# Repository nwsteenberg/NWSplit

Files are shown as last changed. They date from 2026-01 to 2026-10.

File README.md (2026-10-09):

# NWSplit

> A 52-key, column-staggered split ergonomic keyboard developed almost entirely through **Ergogen**.

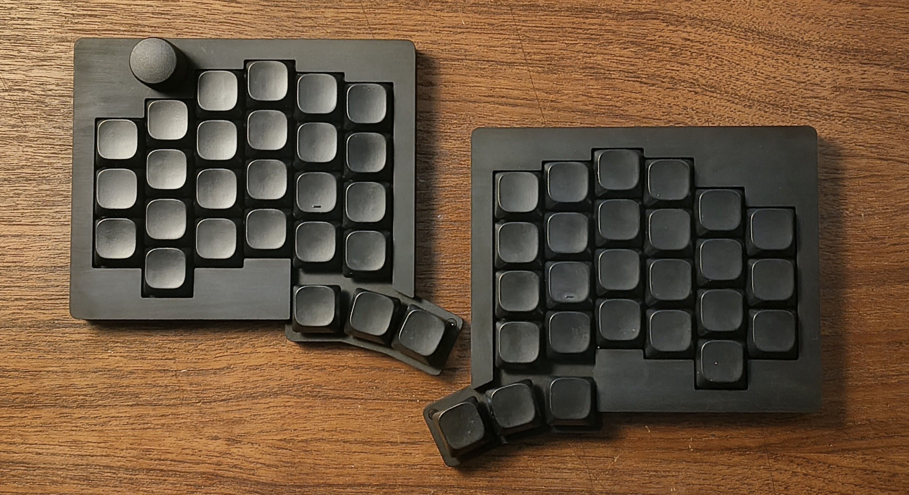
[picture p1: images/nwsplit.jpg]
NWSplit Keyboard


The goal: build the *perfect* keyboard for me. Of course, getting there meant going through a handful of prototypes that didn't quite make the cut. Take a look at the [Graveyard](images/graveyard) to see the keyboards that didn't make the cut.

---

## ✨ Features
* **Declarative:** Designed in [Ergogen](https://ergogen.xyz/) (both case and PCB).
* **Firmware:** Powered by **QMK & VIAL** for real-time keymap customization without flashing.
* **Choc Switches:** Hot-swap support for Kailh Choc v1 and v2 switches.
* **Per-Key RGB:** SK6812 MINI-E lighting support.
* **Extra Inputs:** Optional rotary encoder support (up to 2).

---

## 📂 Repository Structure

* `3d/` — 3D printable models (`.stl`) for the keyboard and expansion modules.
* `firmware/` — Vial/QMK firmware source files and layouts.
* `footprints/` — Custom Ergogen and KiCad footprints.
* `images/` — Renders, wiring diagrams, and build photos.
* `production/` — Ready-to-use PCB production files (Gerbers).
* `traced-pcbs/` — Autogenerated and manually traced KiCad PCB projects.
* `keyboard.yaml` — Ergogen configuration file for the main keyboard.
* `expansion.yaml` — Ergogen configuration file for the expansion modules.

---

## 🛒 Bill of Materials (BOM)

| Component | Description | Quantity | Notes |
| :--- | :--- | :---: | :--- |
| **PCB** | Gerber available in `production/` | 2 | Reversible (left and right use the exact same PCB) |
| **Diodes** | 1N4148, SOD123 | 52 | |
| **MCU** | Waveshare RP2040-Zero | 2 | Clones work too just verify pinout compatibility |
| **TRRS Connector** | PJ320A Jack | 2 | |
| **Switches** | Kailh Choc V1/V2 | 52 | Dont use V2 with guide pin (stock red/blue/brown) |
| **Keycaps** | Low-profile keycaps of choice | 52 | THT or LPF profiles recommended |
| **Heat Inserts** | M2 L3 OD3.5 (or OD3 for resin prints) | 12 | |
| **Per-Key LEDs** | SK6812 MINI-E | 52 | *Optional* |
| **Rotary Encoder** | EC11 / EC12 | 0–2 | *Optional* (supports button click) |
| **Pogo Connectors** | Angled 6-pin Magnetic Pogo Pins | 0–2 | *Optional* (used for experimental modular connections) |

---

## 🚀 Roadmap & TODO

- [ ] **Build Instructions:** Step-by-step assembly guide.
- [ ] **Sandwitch case:** Cheap case option without 3d printing.
- [ ] **Expansion Boards:** 
  - [ ] Trackball module
  - [ ] Trackpad module
- [ ] **Images:** Add build process and final images of the keyboard and expansions.
- [ ] **Graveyard:** Show what keyboards didn't make the cut.

---

## 💡 Inspiration

Throughout the journey the following projects provided a ton of inspiration to create the version of the keyboard as it is today:
* [christianselig/caldera](https://christianselig.com/2024/07/caldera-keyboard/)
* [achyudh/karma](https://github.com/achyudh/karma)
* [carrefinho/forager](https://github.com/carrefinho/forager)

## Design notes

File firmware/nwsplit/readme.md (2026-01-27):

# nwsplit60

NWSplit

*A short description of the keyboard/project*

* Keyboard Maintainer: [Nikolaj W. Steenberg](https://github.com/nwsteenberg)
* Hardware Supported: RP2040 @TODO

Make example for this keyboard (after setting up your build environment):

    make nwsplit:default

Flashing example for this keyboard:

    make nwsplit:default:flash

See the [build environment setup](https://docs.qmk.fm/#/getting_started_build_tools) and the [make instructions](https://docs.qmk.fm/#/getting_started_make_guide) for more information. Brand new to QMK? Start with our [Complete Newbs Guide](https://docs.qmk.fm/#/newbs).

## Bootloader

Enter the bootloader in 3 ways:

* **Bootmagic reset**: Hold down the key at (0,0) in the matrix (usually the top left key or Escape) and plug in the keyboard
* **Physical reset button**: Briefly press the button on the back of the PCB - some may have pads you must short instead
* **Keycode in layout**: Press the key mapped to `QK_BOOT` if it is available

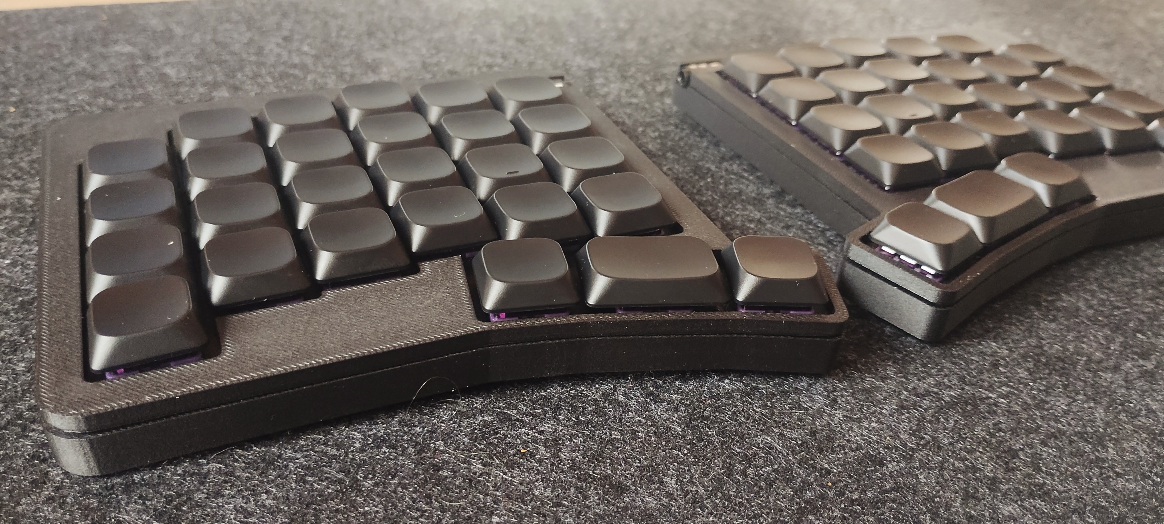
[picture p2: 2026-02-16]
images/graveyard/nwsplit_rev4_2.jpg

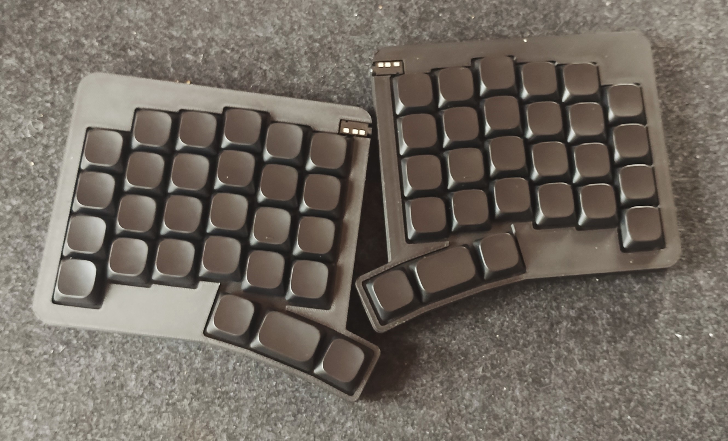
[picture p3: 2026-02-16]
images/graveyard/nwsplit_rev4.jpg

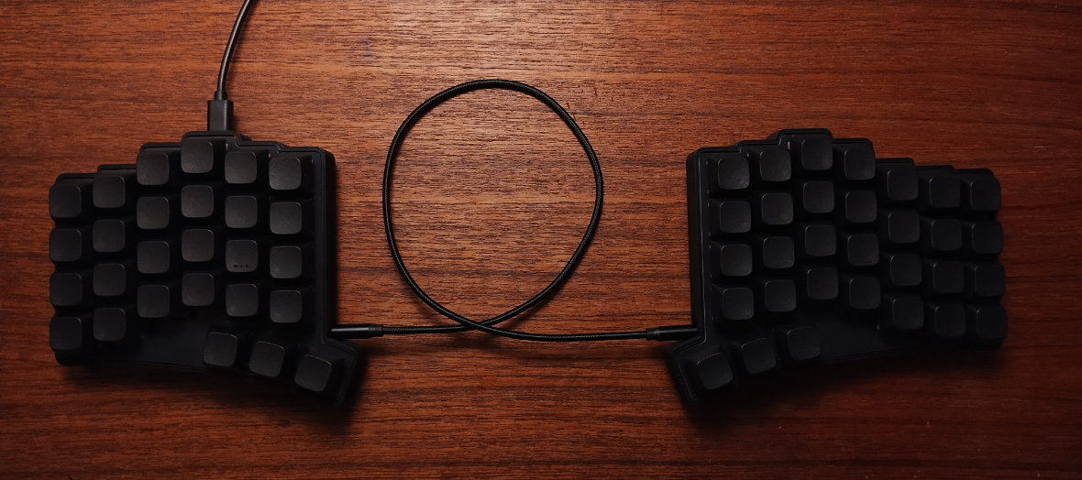
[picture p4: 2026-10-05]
images/graveyard/nwsplit_rev2.png

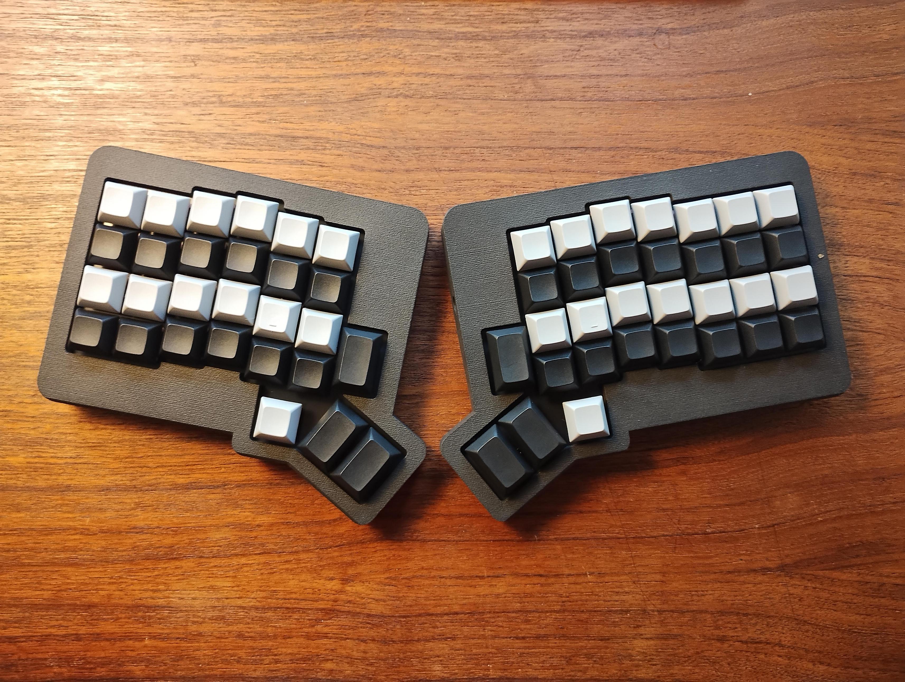
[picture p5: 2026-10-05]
images/graveyard/nwsplit_rev3.jpeg

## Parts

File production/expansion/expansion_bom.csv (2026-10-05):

Designator | Footprint | Quantity | Value | LCSC Part #
C1 | FPC-SMD_FPC05006-09200 | 1 | FPC-SMD_FPC05006-09200 | C479749

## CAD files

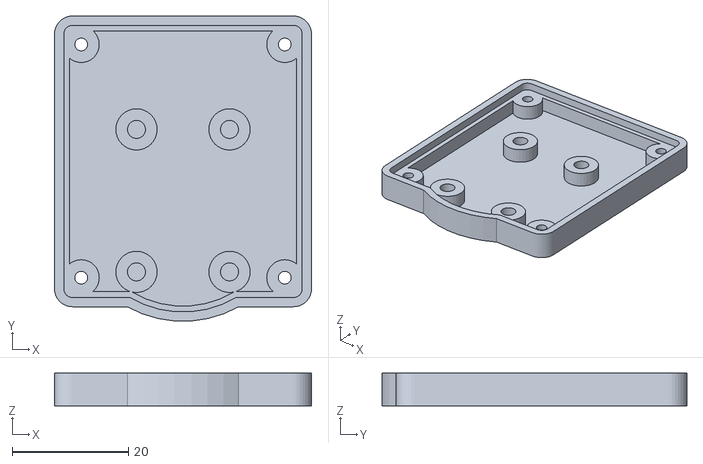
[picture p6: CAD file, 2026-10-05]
3d/expansion/trackball/trackballBase.stl
44.2 x 52.4 x 5.60

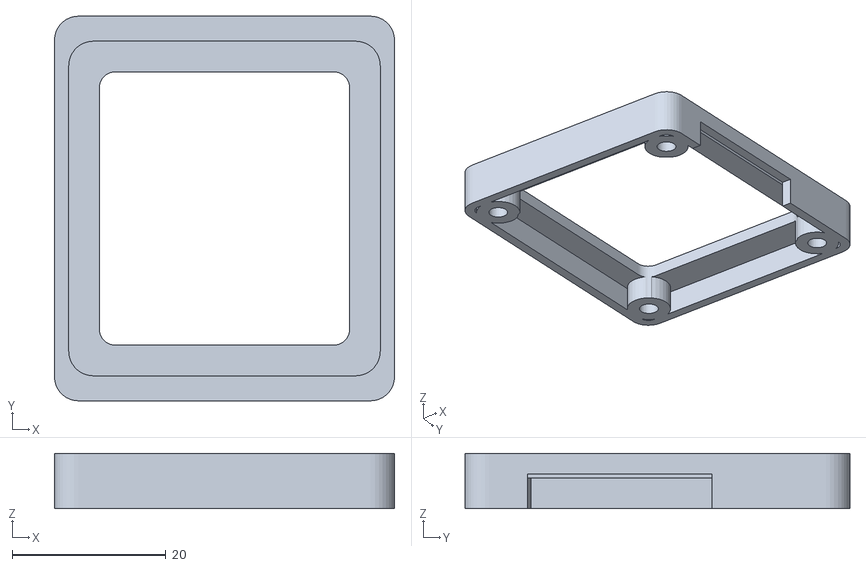
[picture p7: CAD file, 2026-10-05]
3d/expansion/trackpad/trackpadTop.stl
44.2 x 50.0 x 7.20

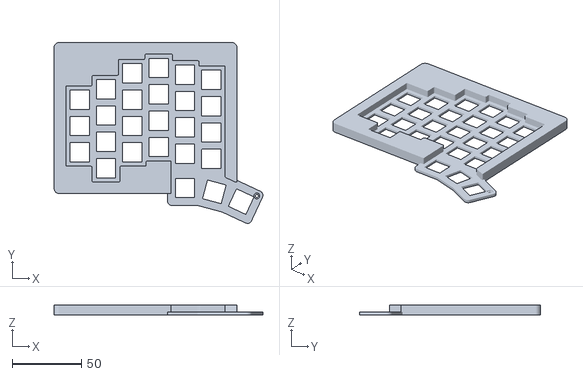
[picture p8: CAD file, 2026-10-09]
3d/keyboard/topLeft.stl
150.7 x 130.4 x 7.20

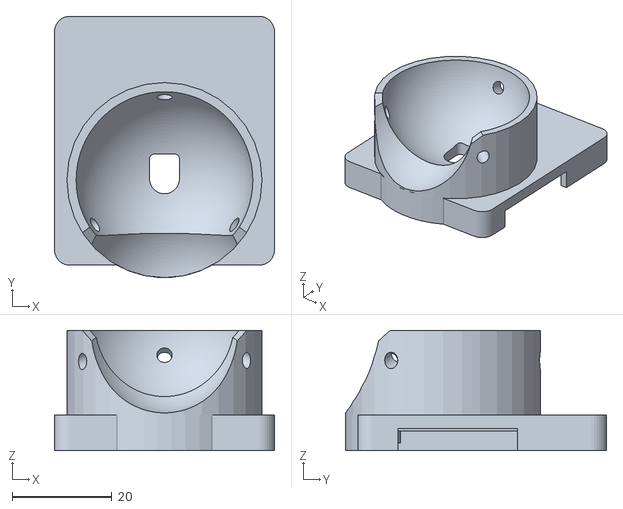
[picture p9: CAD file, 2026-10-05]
3d/expansion/trackball/trackballTop2.stl
44.2 x 52.5 x 24.2

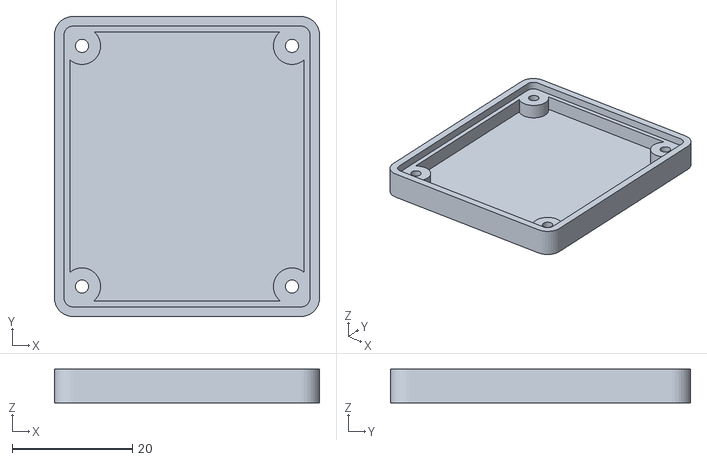
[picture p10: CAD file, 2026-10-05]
3d/expansion/trackpad/trackpadBase.stl
44.2 x 50.0 x 5.60

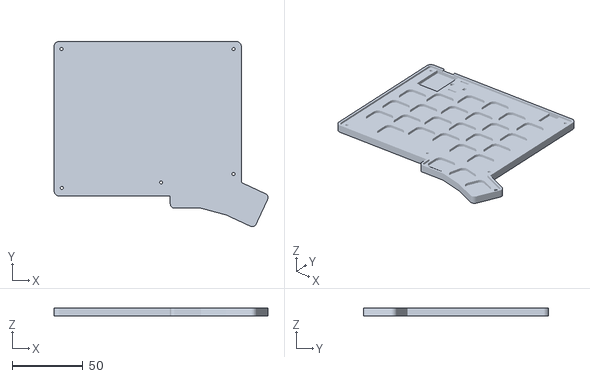
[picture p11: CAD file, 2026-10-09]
3d/keyboard/bottomLeft.stl
150.7 x 130.4 x 5.60

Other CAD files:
3d/keyboard/topRightEncoder.stl
3d/expansion/trackball/trackballTop.stl
3d/keyboard/topLeftEncoder.stl
3d/keyboard/bottomRight.stl
3d/keyboard/topRight.stl
3d/expansion/trackball/trackballTop.blend

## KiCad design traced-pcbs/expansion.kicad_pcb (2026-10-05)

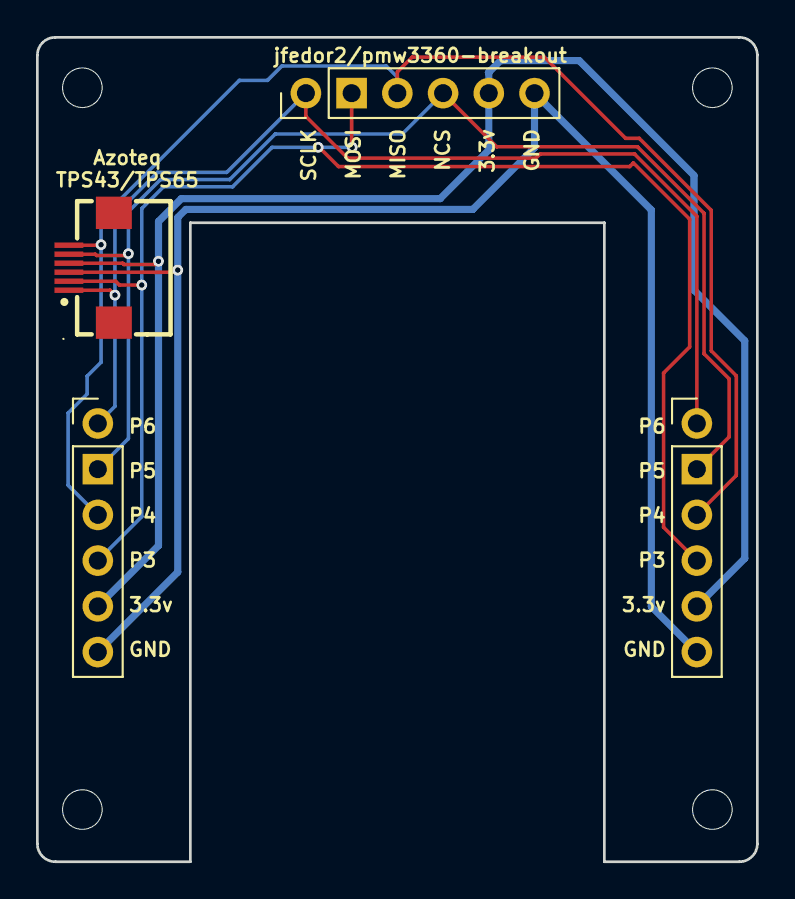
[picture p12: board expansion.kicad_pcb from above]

Board: 2 copper layers, 40.0 x 45.8 mm, 8 parts (0 on the bottom side), 6 nets.

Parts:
C1: FPC-SMD_FPC05006-09200
MH1, MH2, MH3, MH4: mounting_hole_npth
Pin Header 2.54 1x61, Pin Header 2.54 1x62, Pin Header 2.54 1x63: PinHeader_1x06_P2.54mm_Vertical

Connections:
GND: C1.3, Pin Header 2.54 1x61.6, Pin Header 2.54 1x62.6, Pin Header 2.54 1x63.6
P1: C1.1, Pin Header 2.54 1x61.1, Pin Header 2.54 1x62.1, Pin Header 2.54 1x63.1
P2: C1.5, Pin Header 2.54 1x61.2, Pin Header 2.54 1x62.2, Pin Header 2.54 1x63.4
P3: C1.6, Pin Header 2.54 1x61.3, Pin Header 2.54 1x62.3, Pin Header 2.54 1x63.3
P3V3: C1.4, Pin Header 2.54 1x61.5, Pin Header 2.54 1x62.5, Pin Header 2.54 1x63.5
P4: C1.2, Pin Header 2.54 1x61.4, Pin Header 2.54 1x62.4, Pin Header 2.54 1x63.2

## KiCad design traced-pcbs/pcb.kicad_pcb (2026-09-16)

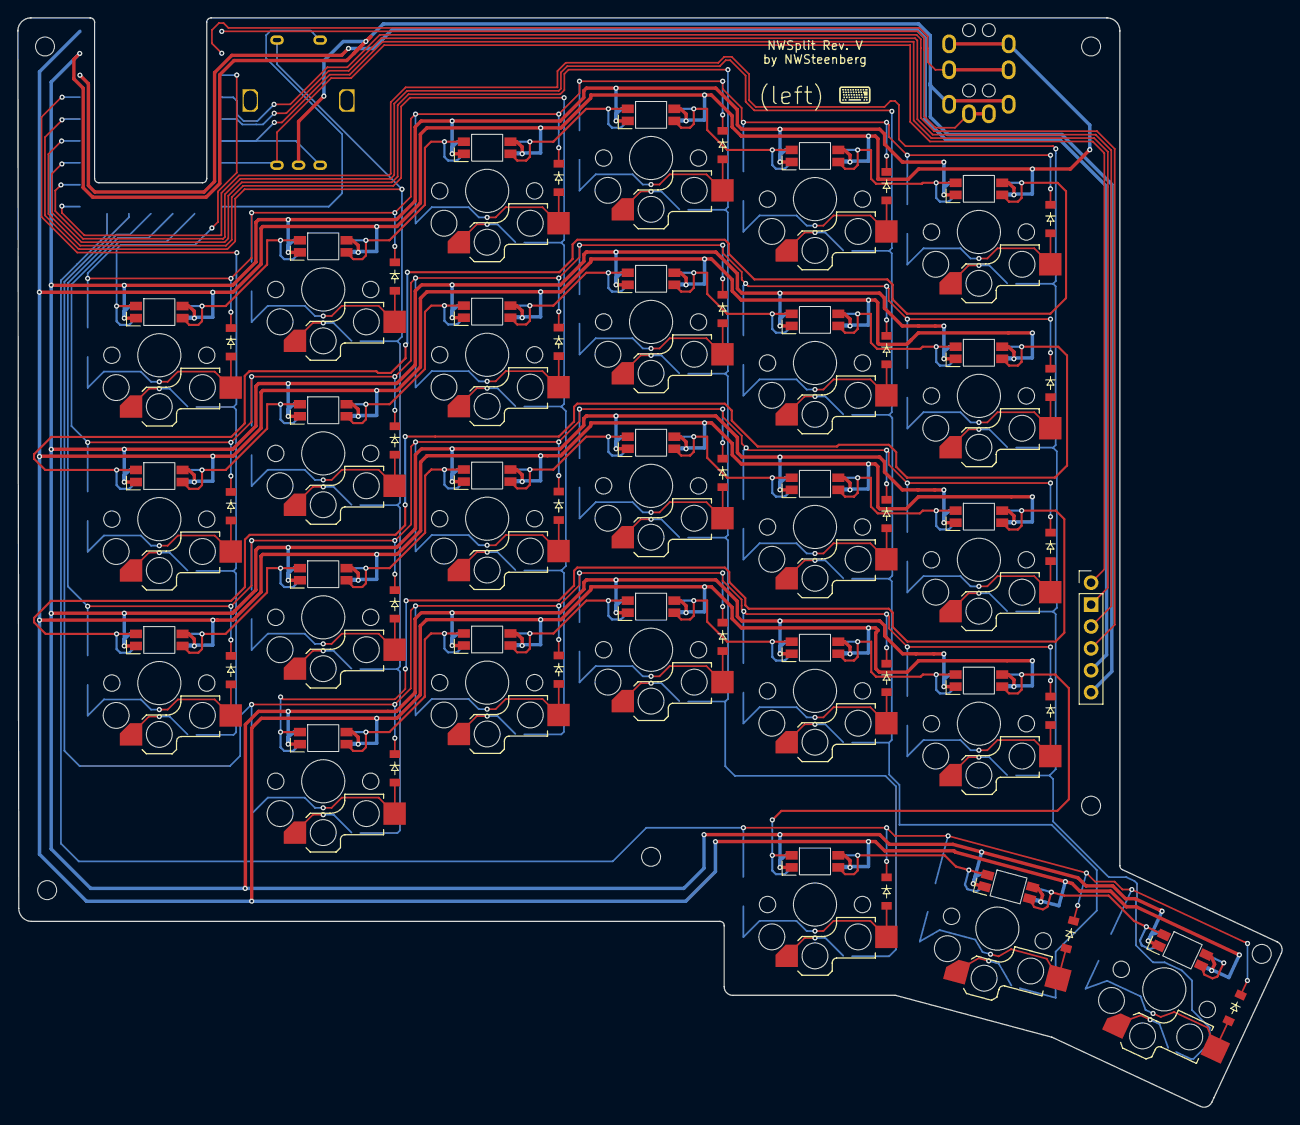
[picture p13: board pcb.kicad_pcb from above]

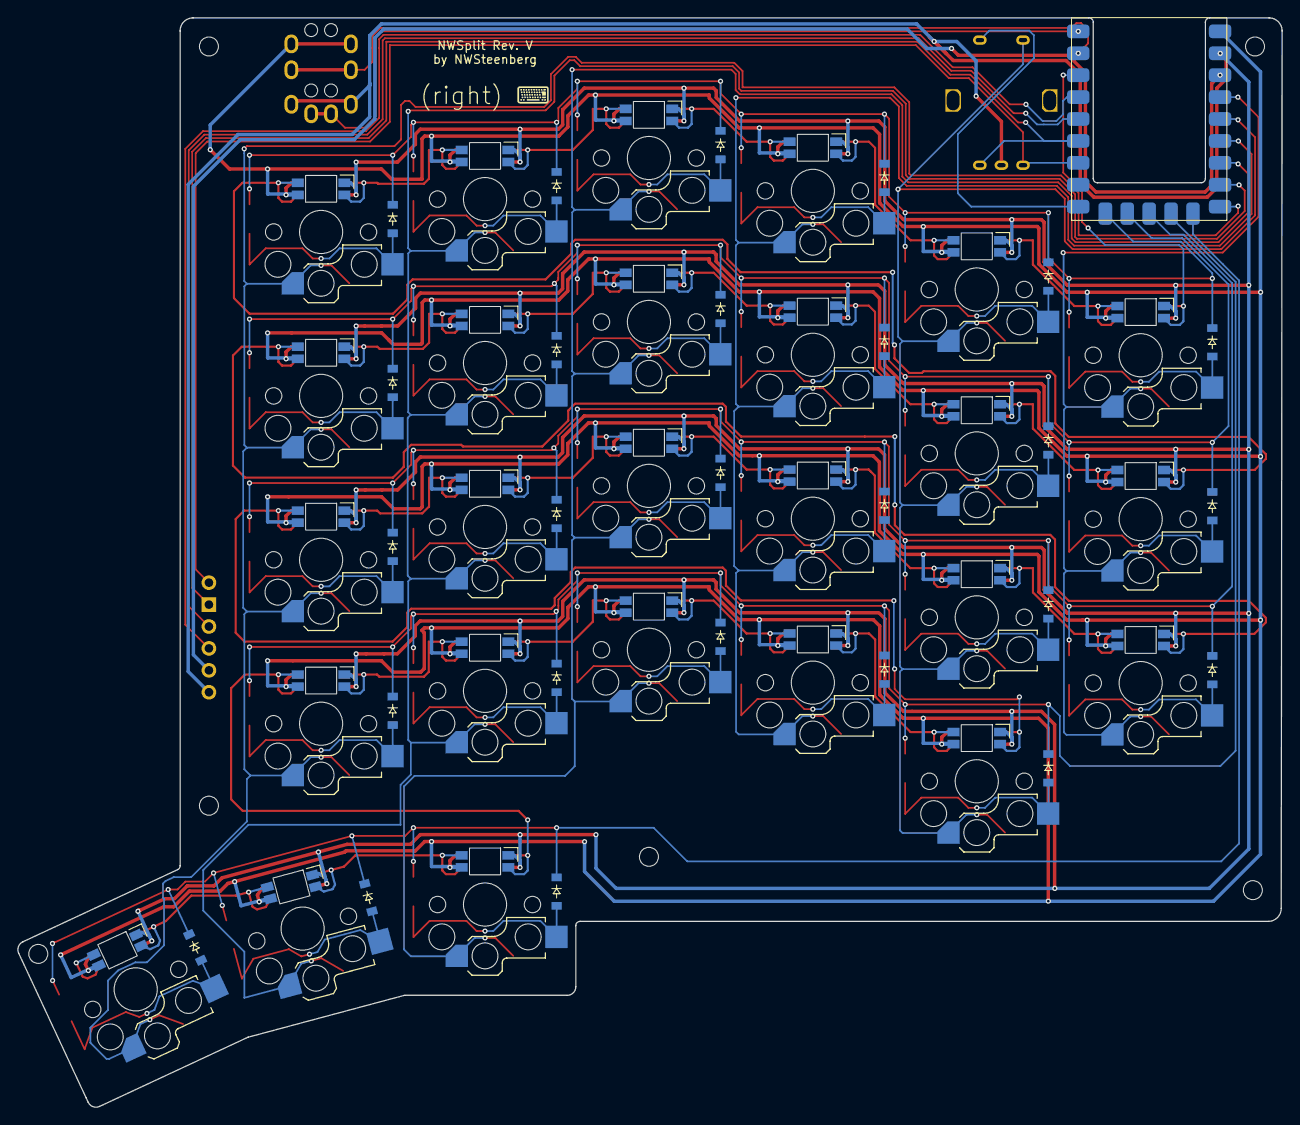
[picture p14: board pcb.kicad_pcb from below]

Board: 2 copper layers, 146.5 x 126.3 mm, 113 parts (78 on the bottom side), 42 nets.

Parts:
D1, D2, D3, D4, D5, D6, D7, D8, D9, D10, D11, D12, D13, D14, D15, D16, D17, D18, D19, D20, D21, D22, D23, D24, D25, D26, D27, D28, D29, D30, D31, D32, D33, D34, D35, D36, D37, D38, D39, D40, D41, D42, D43, D44, D45, D46, D47, D48, D49, D50, D51, D52: diode_tht_sod123
LED1, LED2, LED3, LED4, LED5, LED6, LED7, LED8, LED9, LED10, LED11, LED12, LED13, LED14, LED15, LED16, LED17, LED18, LED19, LED20, LED21, LED22, LED23, LED24, LED25, LED26: led_SK6812mini-e (per-key, reversible)
MH1, MH2, MH3, MH4, MH5, MH6: mounting_hole_npth
Pin Header 2.54 1x61: PinHeader_1x06_P2.54mm_Vertical
RE1: rotary_encoder_ec11_ec12
S1, S2, S3, S4, S5, S6, S7, S8, S9, S10, S11, S12, S13, S14, S15, S16, S17, S18, S19, S20, S21, S22, S23, S24, S25, S26: switch_choc_v1_v2
TRRS1: trrs_pj320a (reversible)

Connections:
GND: LED1.3, LED2.3, LED3.3, LED4.3, LED5.3, LED6.3, LED7.3, LED8.3, LED9.3, LED10.3, LED11.3, LED12.3, LED13.3, LED14.3, LED15.3, LED16.3, LED17.3, LED18.3, LED19.3, LED20.3, LED21.3, LED22.3, LED23.3, LED24.3, LED25.3, LED26.3, Pin Header 2.54 1x61.6, RE1.B, TRRS1.4
GP5: Pin Header 2.54 1x61.2, RE1.A
GP6: Pin Header 2.54 1x61.1, RE1.C
GP9: D3.1, D7.1, D11.1, D15.1, D19.1, D23.1, D29.1, D33.1, D37.1, D41.1, D45.1, D49.1
GP10: D2.1, D6.1, D10.1, D14.1, D18.1, D22.1, D28.1, D32.1, D36.1, D40.1, D44.1, D48.1
GP11: D1.1, D5.1, D9.1, D13.1, D17.1, D21.1, D27.1, D31.1, D35.1, D39.1, D43.1, D47.1
GP12: D4.1, D8.1, D12.1, D16.1, D20.1, D30.1, D34.1, D38.1, D42.1, D46.1
GP13: D24.1, D25.1, D26.1, D50.1, D51.1, D52.1
GP14: S20.1, S21.1, S22.1, S23.1, S26.1
GP15: S16.1, S17.1, S18.1, S19.1, S25.1
GP26: S12.1, S13.1, S14.1, S15.1, S24.1
GP27: S8.1, S9.1, S10.1, S11.1
GP28: RE1.S1, S4.1, S5.1, S6.1, S7.1
GP29: S1.1, S2.1, S3.1
LED_NET: LED1.2, LED2.2, LED2.4, LED3.2, LED3.4, LED4.2, LED4.4, LED5.2, LED5.4, LED6.2, LED6.4, LED7.2, LED7.4, LED8.2, LED8.4, LED9.2, LED9.4, LED10.2, LED10.4, LED11.2, LED11.4, LED12.2, LED12.4, LED13.2, LED13.4, LED14.2, LED14.4, LED15.2, LED15.4, LED16.2, LED16.4, LED17.2, LED17.4, LED18.2, LED18.4, LED19.2, LED19.4, LED20.2, LED20.4, LED21.2, LED21.4, LED22.2, LED22.4, LED23.2, LED23.4, LED24.2, LED24.4, LED25.2, LED25.4, LED26.2, LED26.4
P5V: LED1.1, LED2.1, LED3.1, LED4.1, LED5.1, LED6.1, LED7.1, LED8.1, LED9.1, LED10.1, LED11.1, LED12.1, LED13.1, LED14.1, LED15.1, LED16.1, LED17.1, LED18.1, LED19.1, LED20.1, LED21.1, LED22.1, LED23.1, LED24.1, LED25.1, LED26.1, TRRS1.2
center_only: D25.2, D51.2, S25.2
index_bottom: D16.2, D42.2, S16.2
index_home: D17.2, D43.2, S17.2
index_num: D19.2, D45.2, S19.2
index_top: D18.2, D44.2, S18.2
inner_bottom: D20.2, D46.2, S20.2
inner_home: D21.2, D47.2, S21.2
inner_num: D23.2, D49.2, S23.2
inner_only: D24.2, D50.2, S24.2
inner_top: D22.2, D48.2, S22.2
middle_bottom: D12.2, D38.2, S12.2
middle_home: D13.2, D39.2, S13.2
middle_num: D15.2, D41.2, S15.2
middle_top: D14.2, D40.2, S14.2
outer_home: D1.2, D27.2, S1.2
outer_num: D3.2, D29.2, S3.2
outer_only: D26.2, D52.2, S26.2
outer_top: D2.2, D28.2, S2.2
pinky_bottom: D4.2, D30.2, S4.2
pinky_home: D5.2, D31.2, S5.2
pinky_num: D7.2, D33.2, S7.2
pinky_top: D6.2, D32.2, S6.2
ring_bottom: D8.2, D34.2, S8.2
ring_home: D9.2, D35.2, S9.2
ring_num: D11.2, D37.2, S11.2
ring_top: D10.2, D36.2, S10.2

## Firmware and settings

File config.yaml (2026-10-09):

units:
  outlinePadding: 1

  plateThickness: 1.6
  pcbThickness: 1.6

  keyCutoutDimentions: 13.95

  # Case
  baseHeight: 3
  screwRadius: 1.1 # M2 + 0.2mm buffer
  screwHoleRadius: 1.55
  screwHoleWallThickness: 2
  screwHeadRadius: 2.1 # 4mm + 0.2mm buffer
  fromPlateToTop: 5

  baseWallHeight: baseHeight + pcbThickness
  topWallHeight: 2.2
  wallThickness: 1.6

points:
  zones:
    matrix:
      anchor:
        shift: [40, -180] # Move into KiCAD position
      columns:
        outer.key.column_net: "GP29"
        outer.rows.bottom.skip: true

        pinky.key.column_net: "GP28"
        pinky.key.stagger: 0.4U

        ring.key.column_net: "GP27"
        ring.key.stagger: 0.6U

        middle.key.column_net: "GP26"
        middle.key.stagger: 0.2U

        index.key.column_net: "GP15"
        index.key.stagger: -0.25U

        inner.key.column_net: "GP14"
        inner.key.stagger: -0.2U
      rows:
        bottom.row_net: "GP12"
        home.row_net: "GP11"
        top.row_net: "GP10"
        num.row_net: "GP9"
    thumb:
      anchor:
        ref: matrix_index_bottom
        shift: [0U, -1.3U]
      columns:
        inner:
          key.name: matrix_thumb_inner
          key.column_net: "GP26"
          key.origin: [-0.5U, -0.5U]
        center:
          key.name: matrix_thumb_center
          key.column_net: "GP15"
          key.splay: -15
          key.origin: [-0.5U, -0.5U]
        outer:
          key.name: matrix_thumb_outer
          key.column_net: "GP14"
          key.splay: -10
          key.origin: [-0.5U, -0.5U]
      rows:
        only:
          row_net: "GP13"
    screw_1:
      anchor:
        - ref: matrix_inner_bottom
          shift: [13, -9.5]
    screw_2:
      anchor:
        - ref: matrix_inner_num
          shift: [13, 21.5]
    screw_3:
      anchor:
        - ref: matrix_inner_num
          shift: [-5U-13, 21.5]
    screw_4:
      anchor:
        - ref: matrix_outer_home
          shift: [-13, -24]
    screw_5:
      anchor:
        - ref: matrix_middle_bottom
          shift: [0, -24]
    screw_thumb:
      anchor:
        - ref: matrix_thumb_outer
          shift: [8.5, 8.5]
    knob:
      anchor:
        - ref: matrix_pinky_num
          shift: [-0.15U, 1.15U]
      columns.only.key.column_net: "GP28"
      rows.only.row_net: "GP8"
  mirror:
    ref: matrix_pinky_home
    distance: 270
outlines:
  _keysCutout:
    - what: rectangle
      size: [keyCutoutDimentions, keyCutoutDimentions]
      fillet: 0.1
  _knobCutout:
    - what: rectangle
      size: [14, 15]
      fillet: 3

  _rightSubstitution:
    - what: rectangle
      size: 10U
      where:
        ref: mirror_matrix_middle_home

  _leftSubstitution:
    - what: rectangle
      size: 10U
      where:
        ref: matrix_middle_home

  _bottomKeyCutout:
    - what: rectangle
      size: [16.5, 15.5]
      adjust.shift: [-1.5, -1]
      fillet: 4
  
  _bottomKnobCutout:
    - what: rectangle
      size: [7, 1.5]
      adjust.shift: [0,7.5]
      fillet: 0.5
    - what: rectangle
      size: [7, 1.5]
      adjust.shift: [0,-7]
      fillet: 0.5
    - what: rectangle
      size: [2.3, 3]
      adjust.shift: [5.6,0]
      fillet: 0.5
    - what: rectangle
      size: [2.3, 3]
      adjust.shift: [-5.6,0]
      fillet: 0.5

  _MCUPCBCutout:
    - what: rectangle
      size: [13, 20.5]
      where: /matrix_outer_num/
      adjust.shift: [-1, 27.24+3]
  _MCUTopCutout:
    - what: rectangle
      size: [13, 5]
      where: /matrix_outer_num/
      adjust.shift: [-1, 27.24-4.35]
      operation: stack
    - what: rectangle
      size: [9.5, 12]
      where: /matrix_outer_num/
      adjust.shift: [-1, 27.24+10.75]
      expand: 0.1
      operation: stack
  _MCUBottomCutout:
    - what: rectangle
      size: [18.5, 24]
      where: /matrix_outer_num/
      adjust.shift: [-1, 27.24]
  _MCUUSBCutout:
    - what: rectangle
      size: [9.5, 20]
      where: /matrix_outer_num/
      adjust.shift: [-1, 27.24+10]
  _TRRSCutout:
    - what: rectangle
      size: [9, 25]
      where: /matrix_inner_num/
      adjust: &trrsPosition
        shift: [0, 25]
      fillet: 0.5

  _expansionCutout:
    - what: rectangle
      size: [2.54, 23]
      where: /matrix_inner_home/
      adjust.shift: [13,-9]
      expand: 0.5

  _expansionCutoutTopCase:
    - what: rectangle
      size: [2.54+10, 23]
      where: /matrix_inner_home/
      adjust.shift: [13+5,-9]
      expand: 0.5
    
  _bottomCutout:
    - what: outline
      name: _bottomKeyCutout
      where: /matrix/
      fillet: 0.5
    - what: outline
      name: _bottomKnobCutout
      where: /knob/
    - what: outline
      name: _TRRSCutout

  _knobBaseCutout:
    - what: outline
      name: _knobCutout
      where: /knob/
  _knobLeadsCutout:
    - what: outline
      name: _knobBaseCutout
      expand: 1
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

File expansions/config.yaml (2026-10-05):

units:
  outlinePadding: 1

  plateThickness: 1.6
  pcbThickness: 1.6

  keyCutoutDimentions: 13.95

  # Case
  baseHeight: 3
  screwRadius: 1.1 # M2 + 0.2mm buffer
  screwHoleRadius: 1.55
  screwHoleWallThickness: 2
  screwHeadRadius: 2.1 # 4mm + 0.2mm buffer
  fromPlateToTop: 5

  baseWallHeight: baseHeight + pcbThickness
  topWallHeight: 2.2
  wallThickness: 1.6

points:
  zones:
    expansion:
      anchor: 
    expansion_screw_tbBreakout_1:
      anchor:
        - ref: expansion
          shift: [8,-11.1]
    expansion_screw_tbBreakout_2:
      anchor:
        - ref: expansion
          shift: [8,13.4]
    expansion_screw_tbBreakout_3:
      anchor:
        - ref: expansion
          shift: [-8,-11.1]
    expansion_screw_tbBreakout_4:
      anchor:
        - ref: expansion
          shift: [-8,13.4]
    expansion_screw_base_1:
      anchor:
        - ref: expansion
          shift: [17.5,-12.1]
    expansion_screw_base_2:
      anchor:
        - ref: expansion
          shift: [-17.5,28]
    expansion_screw_base_3:
      anchor:
        - ref: expansion
          shift: [-17.5,-12.1]
    expansion_screw_base_4:
      anchor:
        - ref: expansion
          shift: [17.5,28]
    trackpadCenter:
      anchor:
        - ref: expansion
          shift: [0,0]

outlines:
  _baseScrews:
    - what: circle
      radius: screwRadius
      where: /^expansion_screw_base/

  _topScrews:
    - what: circle
      radius: screwHoleRadius
      where: /^expansion_screw_base/

  _trackBallSensorCutout:
  - what: rectangle
    where: expansion
    size: [13, 19]
    adjust.shift: [0, 0]
    fillet: 0.5
  _trackBallLensCutout:
  - what: rectangle
    where: expansion
    size: [19.5, 22]
    adjust.shift: [0, 0.25]
    fillet: 7
  
  _trackBallOpticCutout:
  - what: rectangle
    size: [4, 4]
    where: expansion
    adjust.shift: [0,0.25+2]
  - what: circle
    radius: 2
    adjust.shift: [0,0.25]
    where: expansion
    fillet: 0.1
    expand: 1

  _pcbOutline:
  - what: rectangle
    where: expansion
    size: [38, 34+9.8]
    adjust.shift: [0,3+(9.8/2)]
    expand: outlinePadding
  
  _trackpadRef:
  - what: rectangle
    where: trackpadCenter
    adjust.shift: [0,3+(9.8/2)]
    size: [43.3+0.2, 40.3+0.2]
    fillet: 3.2
    adjust.rotate: 90
  
  _trackpadSeat:
  - what: outline
    name: _trackpadRef
    expand: -4
    fillet: 2

  _pcbOutlineWithCutout:
  - what: outline
    name: _pcbOutline
  - what: rectangle
    where: expansion
    size: [23, 35+4]
    adjust.shift: [0,3-(4/2)]
    operation: subtract
  
  _trackpadBase:
  - what: outline
    name: _pcbOutline
    expand: 0.5
  
  _trackpadPCBSeat:
  - what: outline
    name: _trackpadBase
    expand: -1
  - what: outline
    name: _trackpadBase
    operation: stack

  _trackpadBaseWalls:
    - what: outline
      name: _trackpadBase
      expand: wallThickness
    - what: outline
      name: _trackpadBase
      operation: subtract

  _trackpadBaseStandoffs:
    - what: outline
      name: _baseScrews
      expand: screwHoleWallThickness
    - what: outline
      name: _baseScrews
      operation: subtract

  _trackballHousingBase:
  - what: circle
    where: expansion
    radius: 18
  _trackballHousingBaseWithWalls:
  - what: circle
    where: expansion
    radius: 18
    expand: wallThickness

  _trackballBase:
  - what: outline
    name: _pcbOutline
    expand: 0.5
  - what: outline
    name: _trackballHousingBase
  
  _trackballPCBSeat:
  - what: outline
    name: _trackballBase
    expand: -1
  - what: outline
    name: _trackballBase
    operation: stack

  _trackballBaseWalls:
    - what: outline
      name: _trackballBase
      expand: wallThickness
    - what: outline
      name: _trackballBase
      operation: subtract

  _screwRecessBase:
    - what: circle
      radius: screwHeadRadius
      where: /^expansion_screw_base/

  _trackballBreakoutScrews:
    - what: circle
      radius: screwHoleRadius
      where: /^expansion_screw_tbBreakout/

  _trackballBaseStandoffs:
    - what: outline
      name: _baseScrews
    - what: outline
      name: _trackballBreakoutScrews
      expand: screwHoleWallThickness
    - what: outline
      name: _baseScrews
      operation: subtract
    - what: outline
      name: _trackballBreakoutScrews
      operation: subtract

  _topStandoffs:
    - what: outline
      name: _topScrews
      expand: screwHoleWallThickness
    - what: outline
      name: _topScrews
      operation: subtract

  _expansionSideCutout:
    - what: rectangle
      size: [2.54+10, 23]
      where: expansion
      adjust.shift: [20-3.36+5, 3]
      expand: 0.5
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

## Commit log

2026-01-27 First iteration of keyboard
    [bottom.stl, bottomL.stl, bottomR.stl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]
2026-02-05 Updated after case changes
    [bottom.stl, bottomL.stl, bottomR.stl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]
2026-03-02 [CASE] * Changed baseheight to 1 * Removed wallAroundKeys * Remove material at thumb buttons
2026-03-31 Updated case: * bigger platform for pcb * standoffs for bottom (heated inserts)
2026-03-31 Updated case using ergogen
    [bottom.stl, bottomL.stl, bottomR.stl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]
2026-04-01 Cleaned up repo and setup artifacts for github-actions. Added initial ergogen action
    [bottom.stl, bottomL.stl, bottomR.stl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]
2026-04-01 Add ceoloide ergogen-footprints as submodule
2026-07-05 General rework of Ergogen: * More aggressive stagger * Thumb cluster is now 3x 1U * Reworked entire outline, case and PCB * Reworked RP2040zero footprint * TRRS -> USB breakout * Added per-key RGB
    [leftPCB-B_Cu.gbr, leftPCB-B_Mask.gbr, leftPCB-B_Paste.gbr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]
2026-07-13 [#4] Changed Ergogen config for serial voltage
2026-07-23 [#7] * Refactored pins to fit pro micro rp2040 (and general pro micro layout) * Commented out cases due to WIP
    [#5]
    * Added custom 16p USB-C footprint
    * Co-located with breakout (both supported)
    [#9]
    * Fixed up outputs a bit
    [config.yaml]
2026-07-25 [#7] * Added Reset, Power and battery setup * Moved screws a bit to support battery compartment
    [config.yaml]
2026-08-15 [#11] Reworked heat-inserts to self-tapping screws [#7] Reworked Ergogen to fit pro-micro instead of rp2040-zero mcu
    [config.yaml]
2026-08-17 General housekeeping
    [pcbLeft.kicad_pcb, pcbRight.kicad_pcb]
2026-09-01 Major backpedalling - Back with the rp2040 zero - out with pro micro. In with rotary encoders and expansion - out with wireless hardware. And then ditch the outer bottom button. We dont want you here
    [pcb.kicad_pcb]
2026-09-01 fixed the pin header name
    [config.yaml]
2026-09-02 Added pointing device and fixed up stuff
    [config.h, keymap.c]
2026-09-05 Fixed pin references in pin-header 6 pin
2026-09-10 Fixed up rotary encoder (only left by default)
    [keymap.c]
2026-09-10 Fixed up encoder for qmk
2026-09-10 USB -> TRRS Fixed up firmware and pin mapping New PCB
    [config.h, config.yaml]
2026-09-10 Fix rotary encoder setup in keyboard.json
2026-09-16 Housekeeping!! Aaand started up on expansions
    [expansionBase.stl, expansionTop.stl, extensionTop.blend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]
2026-09-17 Updated the trackball a bit
    [expansionTop.stl, extensionTop.blend]
2026-09-17 Added rotate to trackball sensor (will be around 90 degrees counter clockwise). Might tweak in future
2026-09-19 Fixed bottom right tolerances for mcu
    [config.yaml]
2026-09-19 Fixed led pin
2026-09-19 Updated firmware (rotary encoder fixes)
    [keymap.c]
2026-09-19 Fixed up trackball setup
    [config.h]
2026-09-19 Added features to qmk (pointing device)
2026-09-20 Fixed up some stuff - housekeeping!!!
    [config.h, keymap.c]
2026-09-20 Disable encoder of right split
2026-09-20 Added dummy pins for right rotary encoder
2026-09-20 Claude take the wheel!
2026-09-20 Fixes to start bootloader
    [config.h]
2026-09-20 Custom SPI using PIO
2026-09-21 Removed custom SPI stuff
2026-09-27 Updated README. Worked a bit on trackball and added FN layer for keymap
    [expansionBase.stl, expansionTop.stl, extensionTop.blend]
2026-09-27 Also add layers to encoder maps
2026-10-05 Major work on expansions. Initial testing started
    [bom.csv, expansionBase.stl, expansionTop.stl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]
2026-10-09 Restructured repo entirely: * Moved expansions to root (share folders with keyboard) * Renamed a bit here and there. * Added STL files for keyboard into repo * Updated readme (added some flair)
    [bottomLeft.stl, bottomRight.stl, expansion.kicad_pcb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]
2026-10-09 [3d] Added right/left with and without encoder
    [topLeft.stl, topLeftEncoder.stl, topRightEncoder.stl]
2026-10-20 Changed keymap for mouse buttons
